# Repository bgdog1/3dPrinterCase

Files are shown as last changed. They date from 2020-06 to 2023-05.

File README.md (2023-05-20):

# 3dPrinterCase
Stand Alone Main Control Case with Modular Mounts for Various Mainboards, Display's, RPi's, Fans amd MORE!

Read the Case Guide 

Summary

I designed this Control Box out of the need for one. All the cases I found were specific to one machine and one mainboard. So if I wanted to change the mainboard or modify the machine design it quickly became obsolete. My idea behind this one is to print it once and be able to make changes as I need them. Change the screen, mainboard or RPi, just print a new mount, install it and continue. I don't have to reprint the entire thing.

The component mounts are removable and changeable so it is very versatile. I currently have plans to put this on 4 printers so the design will change from time to time. Hopefully getting better each time, so add this to your watch list. I have included mounts for the SKR mainboard's, RP3 and 4, and displays that i have and can verify fit. If I don't have it listed yet then it isnt quite ready, Sorry.

LCD Displays Currently Supported:

* LCD12864 the Original Creality Display
* TFT35 Touchscreen: BTT TFT35 V3.0 Touch Screen Display
* TFT35 Touchscreen: BTT TFT35 E3 V3.0 Touch Screen Display
* TFT35 Touchscreen: BTT TFT35 V2.0 Touch Screen Display
* More to come

For the most recent updates on my projects, join my group:
* https://www.facebook.com/groups/3DPrinterModding/

If you would like to support my work, you can use the link below. All Tips go back into the projects to be able to support more hardware. PAYPAL Link:

http://www.paypal.me/bgdog1

Currently working on:
+ Ender 5 Plus Base Case (bottom enclosure)
+ Case 6.0 Versions ALL Versions

The following files have been contributed to this project by these people. Special Thanks!

VERSION HISTORY and FUTURE DIRECTION:
All PRINTERS
- V2.0 - The first Uploads
- V2.1 - Raised the rear fan off the base for larger wire opening
- V3.0 - Customizable EVERYTHING so you can customize the set up even more. Also the Creality boards will fit in this case!!!
- V4.0 - All wiring is now internal and the entire REAR Panel print separate to be able to custmize it completely to the users needs!
- V5.0 - Reworked V3.0 Case to have Case V4.0 Rear Panel and Upper Deck
- V6.0 - Under construction. Will have larger bay for newer mainboards.

ENDER 5 PLUS

5/16/2023
+ E5Plus - Front Skirt 6 Sided 10mm wUSB Switch
+ E5Plus - Front Skirt 6 Sided 10mm
+ E5Plus - Front Skirt 6 Sided 10mm wCenter USB
+ E5Plus - Front Skirt 6 Sided 10mm wSwitch
+ E5Plus - Front Skirt 6 Sided 10mm wTempController
+ E5Plus - Front Skirt 6 Sided 10mm wTempControlUSB Switch
+ E5Plus - Rear Skirt 6 Sided 10mm wIEC
+ E5Plus - Rear Skirt 6 Sided 10mm wStock IEC
+ E5Plus - Rear Skirt 6 Sided 10mm
+ E5Plus - Side Skirt 6 Sided 10mm  wRJ45 Bottom
+ E5Plus - Side Skirt 6 Sided 10mm  wRJ45 Top
+ E5Plus - Side Skirt 6 Sided 10mm wTool Holder 1
+ E5Plus - Side Skirt 6 Sided 10mm

5/14/2023
+ Added E5P Single Control Box wFloor V2
+ Added E5Plus - Center Piece - Klipper Logo
+ Added E5Plus - Center Piece - Marlin Logo
+ Added E5Plus - Center Piece - RPi Logo
+ Added E5Plus - Center Piece - No Logo

5/13/2023
+ Added Ender 5 Plus - Base Case Component - Feet 

ALL PRINTERS
3/12/2022
+ Added Mainboard Mount - SKR V2.0

5/5/2021
+ Added TFT 5in RPi Screen Mount
+ Added TFT 5in RPi Screen Cover

3/16/2021 _ Case XL Exclusive Parts
+ Added Front Vent XL - GTR Slots
+ Added Main Body V5_0 XL GTR
+ Added Mainboard Mount XL GTR - SKR GTR V1.0dy V5_0 XL GTR
+ Added XL RPi 7in Screen Mount Lid - BTT GTR

2/7/2021
+ Added Mini Case V1.0
+ Added Mini Case - Base
+ Added Mini Case - Lid
+ Added Mini Case - BLANK Rear Panel.F3D
+ Added Mini Case - BLANK Rear Panel.STL
+ Added Display Mount Mini - Blank.F3D
+ Added Display Mount Mini - Blank.STL
+ Added Display Mount Mini - LCD12864 Stock.F3D
+ Added Display Mount Mini - LCD12864 Stock.STL

12/29/2020
+ Added Mainboard Mount - MKS GenL V1
+ Added Mainboard Mount - MKS SGenL V2
+ Added Display Mount - TFT50V30 Flush Main  Body
+ Added Display Mount XL - TFT50V30 Flush Main  Body
+ Added Display Mount - TFT50V30 Cover

10/6/2020
+ Added Rear Panel - 92mm Fan
+ Added Rear Fan External Cover 100x25mm
+ Added Rear Fan External Cover 92mm
+ Added Rear Fan External Cover 90mm
+ Added Rear Fan External Cover 80mm

10/4/2020
+ Added XL RPi 7in Screen Mount Lid
+ Added Display Mount - TFT35E3V30 SD Access Cover V2
+ Added Display Mount - TFT35E3V30 SD Access Cover V3

9/20/2020 - Starting to rework the Bases for more options
+ Added Base Front - Standard 2pc V2
+ Added Base Front - Standard 2pc V2 wSwitch
+ Added Base Rear -Standard 2pc V2
+ Added Base Rear -Standard 2pc V2 wIEC Connector
+ Added Base - Standard V2
+ Added Base - Standard V2 wIEC Connector
+ Added Base - Standard V2 wIEC and Switch

9/11/2020
+ Added Mainboard Mount Pro - Duet Wifi

9/8/2020
+ Added Display Mount XL - TFT70V30 SD Access Base
+ Added Display Mount XL - TFT70V30 SD Access Cover
+ Added Display Mount XL - Blank
+ Added Display Mount XL - Blank.F3D
+ Added Front Vent XL - Blank
+ Added Front Vent XL - Blank.F3D
+ Added Front Vent XL - BTT Slots

9/4/2020
+ Added Simple Case V2 - Main Body
+ Added Simple Case V2 - Back
+ Added Simple Case V2 - Back.F3D
+ Added Simple Case V2 - Lid
+ Added Simple Case V2 - Lid.F3D

9/3/2020
 + Added Under Table Mainboard Case - Creality V2_X
 + Added Under Table Mainboard Lid - Creality V2_X
 + Added Under Table Mainboard Case - Main Body
 + Added Under Table Mainboard Case - Lid
 + Added Under Table Mainboard Case - Lid.F3D
 + Added Under Table Mainboard Case - Back
 + Added Under Table Mainboard Case - Back.F3D

8/31/2020
+ Added Main Body V5_0 XL
+ Added Main Body Front Pro V5_0 - 2 pc Standard
+ Added Main Body Rear Pro V5_0 - 2 pc Standard

8/29/2020
+ Added Main Body V5_0 XL Compact
+ Added Base Stand XL Compact - Tall wSwitch

8/28/2020
+ Added Main Body V5_0 Pro Standard

8/19/2020
+ Added Mainboard Mount - SKR 1.4 wWIFI

8/15/2020
+ Added Main Body Front V5_0 Standard_2pc
+ Added Main Body Rear V5_0 Standard_2pc
+ Added Main Body V5_0 Compact
+ Added Display Mount - TFT70V30 SD Access Base
+ Added Display Mount - TFT70V30 SD Access Cover
+ Added Display Mount - TFT70V30 SD Access Cover

8/9/2020
+ Uploaded Old Pro Cases to Case XL folder
+ Added Base Stand Front Standard - Tall 2pc_wSwitch
+ Added Base Stand Rear Standard - Tall 2pc_wSwitch
+ Added Base Stand Standard - Tall wSwitch_IEC
+ Added Main Body V5_0 Standard

7/29/2020
- Removed V3.0 Pro Version items
- Removed V4.0 Pro Version items

7/26/2020
+ Added Display Mount - RepRap LCD12864 SD Access Cover
+ Added Display Mount - RepRap12864 SD Access  Spacer
+ Added Display Mount - RepRap12864 SD Access Main Body

7/22/2020
+ Added Base Stand - MeanWell 600w SE600 PSU Full with Switch and IEC connector
+ Added Base Stand - MeanWell 600w SE600 PSU OptionA NO Switch but has IEC connector
+ Added Base Stand - MeanWell 600w SE600 PSU OptionB NO Switch and  NO IEC connector

6/7/2020
+ Added Display Mount - TFT24V1_1 Main Body SD Access
+ Added Display Mount - TFT24V1_1 Spacer SD Access
+ Added Display Mount - TFT24V1_1 Cover SD Access
+ Added Display Mount - TFT24V1_1 Cover SD Access.F3D

6/4/2020
+ Added Upper Level Mount - SSR_1
+ Added Upper Level Mount - SSR_2
+ Added Press in Fastener for 2pc.stl
+ Added CPU Mount - Orange Pi Lite.stl

6/2/2020
+ Added Mainboard Mount V4_0 - MKSGenL_centered
+ Added Mainboard Mount V4_0 - MKSGenL_offset

5/24/2020
+ Added Base Stand Front Standard - Slim 2pc_wSwitch
+ Added Base Stand Rear Standard - Slim 2pc_wSwitch

12/29/2019
+ Uploaded original files

NOTES: The mount for the BTT SKR V1.3 also fits the BTT SKR V1.4, V1.4 Turbo, and V3 Board.

If you would like to support my work, you can use the link below.
All Tips go back into the projects to be able to support more hardware.
PAYPAL Link:

http://www.paypal.me/bgdog1

Thank you!

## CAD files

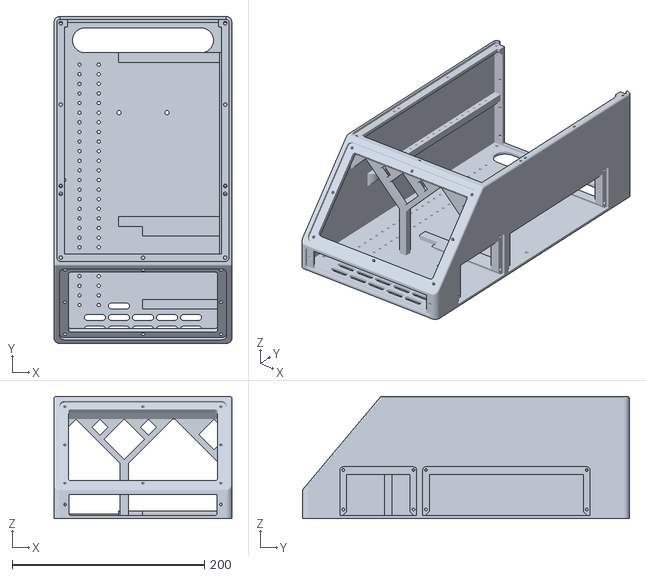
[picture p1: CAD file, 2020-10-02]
Case - PRO V5.0/Main Body V5_0 Pro Standard.stl
185.0 x 340.0 x 127.0

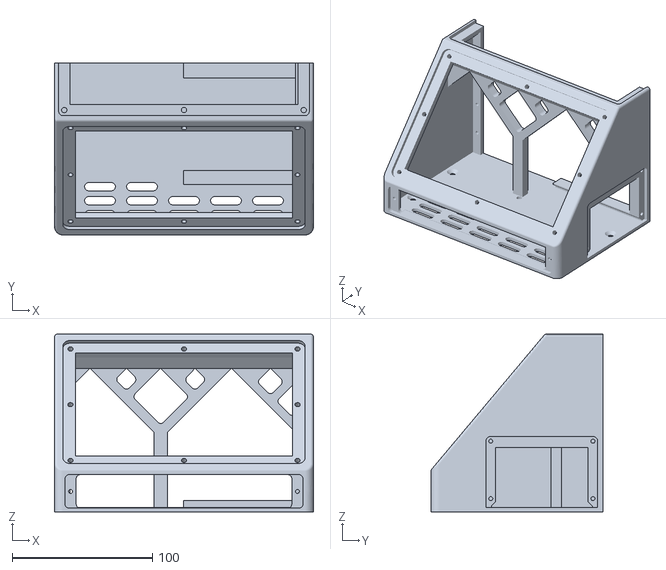
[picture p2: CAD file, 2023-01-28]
Case - Standard V5.X - 2 Piece/Main Body Front V5_1 Standard_2pc.stl
185.0 x 122.8 x 127.0

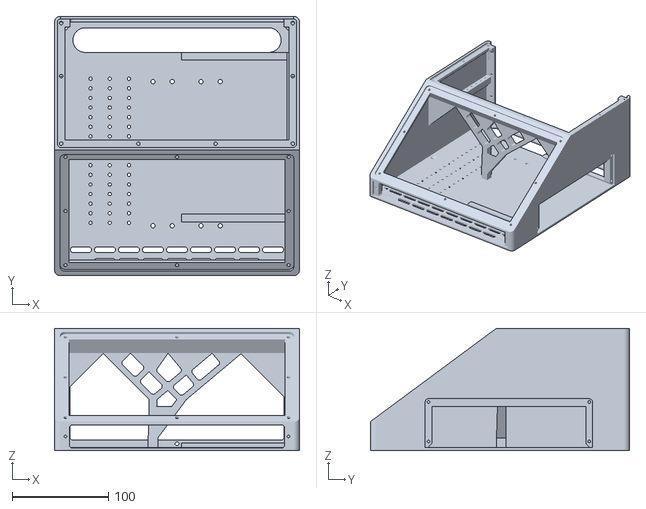
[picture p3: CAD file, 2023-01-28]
Case - XL Compact V5.X/Main Body V5_1 XL Compact.stl
255.0 x 270.0 x 127.0

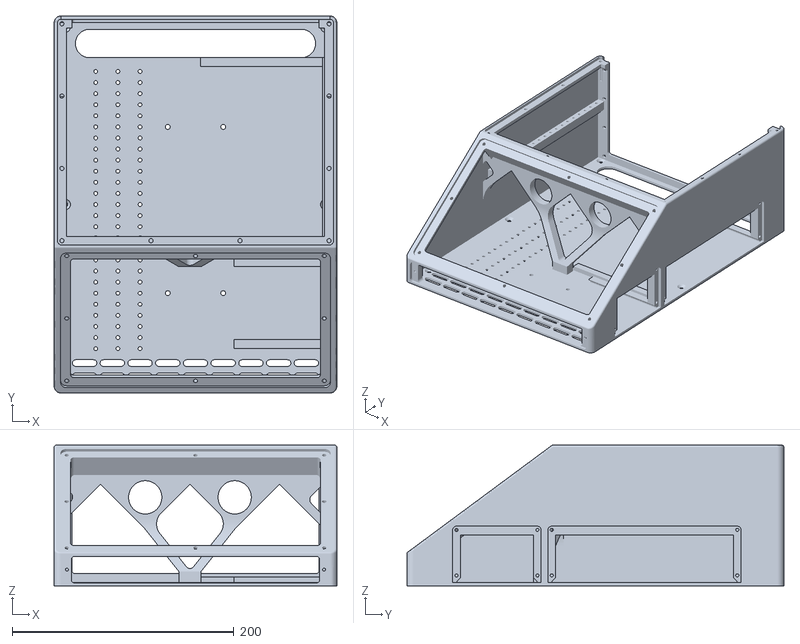
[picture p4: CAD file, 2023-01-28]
Case - XL V5.X/Main Body V5_1 XL.stl
255.0 x 340.0 x 127.0

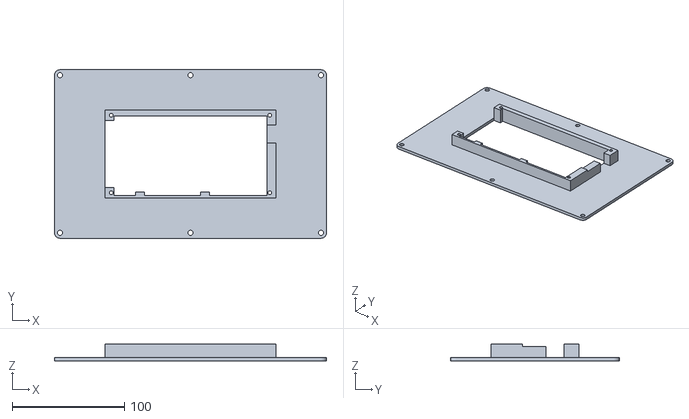
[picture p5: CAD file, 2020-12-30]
Display Mounts - XL/Display Mount XL - TFT50V30 Flush Main Body.stl
242.0 x 150.0 x 15.0

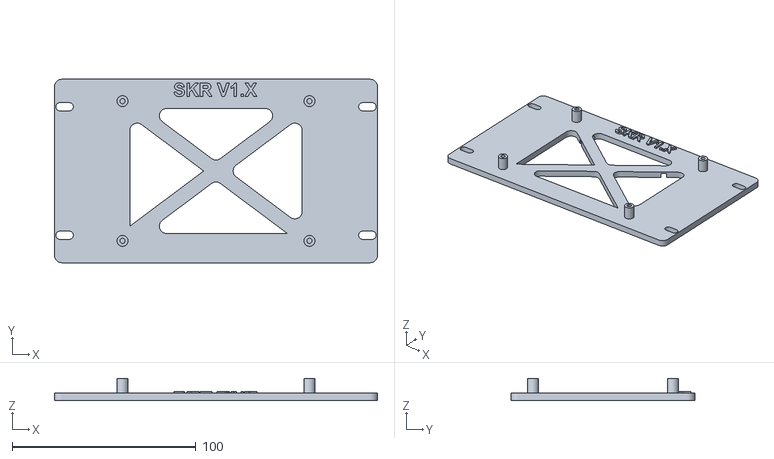
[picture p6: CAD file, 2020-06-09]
Mainboard Mounts - Case 4.0/Mainboard Mount V4_0 - SKRv1.X_centered.stl
176.0 x 100.0 x 12.0

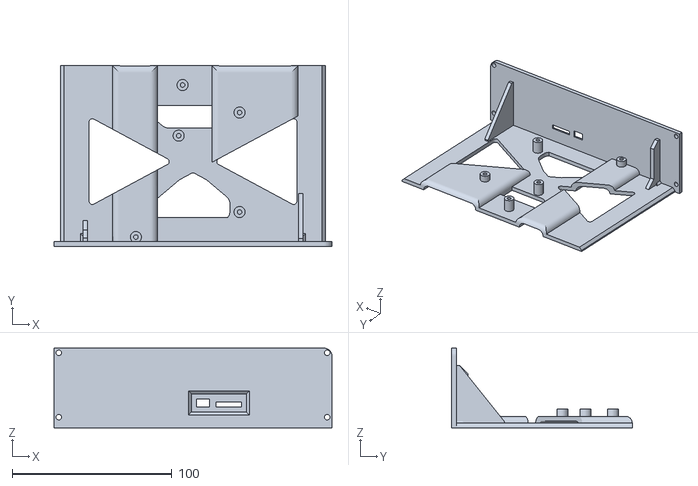
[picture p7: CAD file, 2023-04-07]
Mainboard Mounts - Pro and XL/Mainboard Mount Pro - Creality 115_SKR E3.stl
174.0 x 113.0 x 50.0

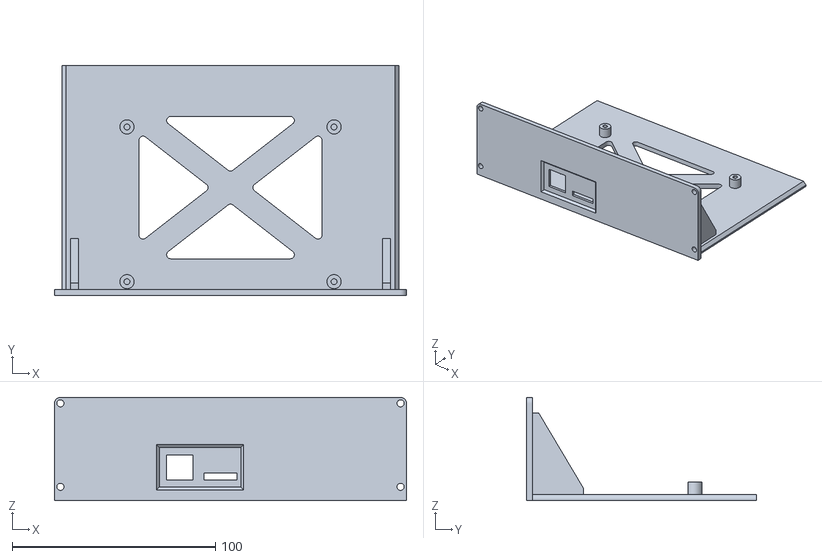
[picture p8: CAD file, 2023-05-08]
Mainboard Mounts for Pro and XL (Same) V5.x Cases/Mainboard Mount XL V5 - SKR V1.X.stl
173.1 x 113.0 x 50.7

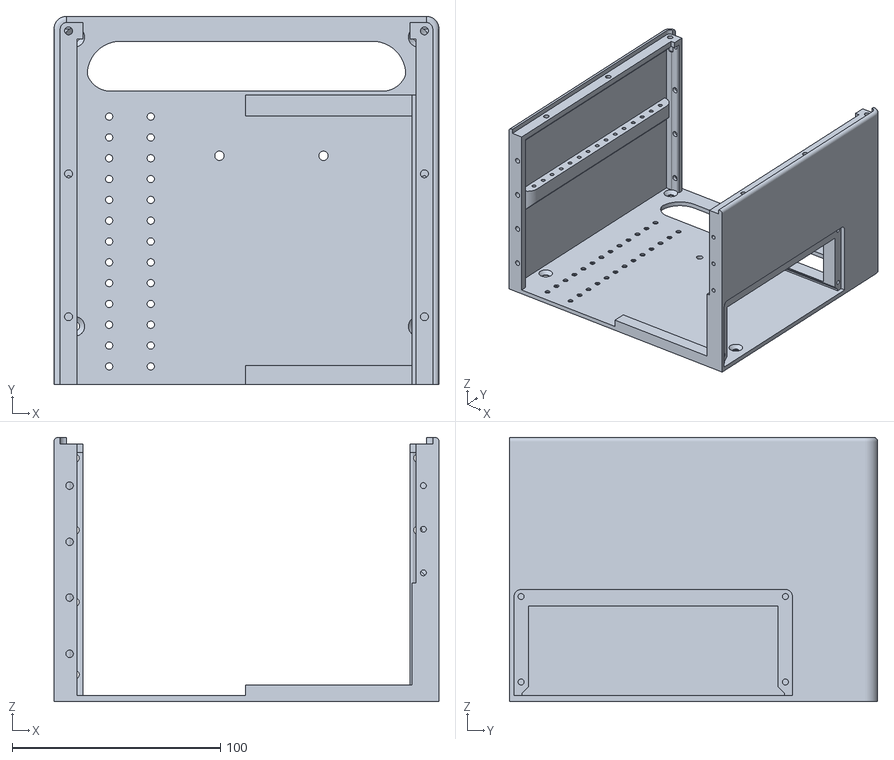
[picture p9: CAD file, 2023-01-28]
Case - Standard V5.X - 2 Piece/Main Body Rear V5_1 Standard_2pc.stl
185.0 x 177.0 x 127.0

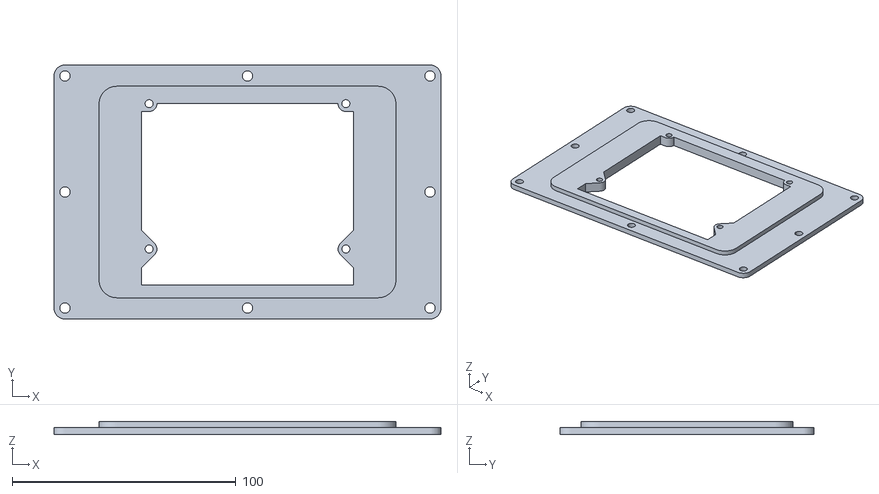
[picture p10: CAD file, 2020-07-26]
Display Mounts - Universal/Display Mount - RepRap12864 SD Access Main Body.stl
173.1 x 113.6 x 5.60

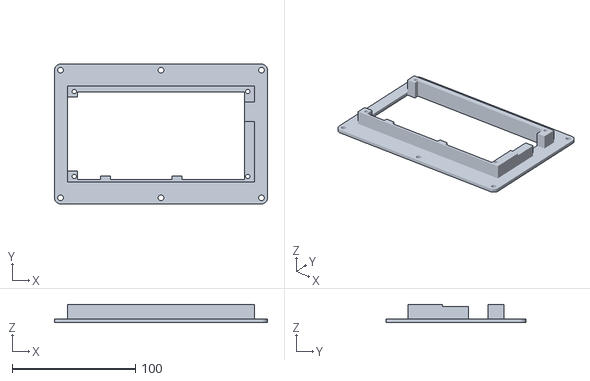
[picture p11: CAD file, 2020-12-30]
Display Mounts/Display Mount - TFT50V30 Flush Main Body.stl
173.1 x 113.6 x 15.0

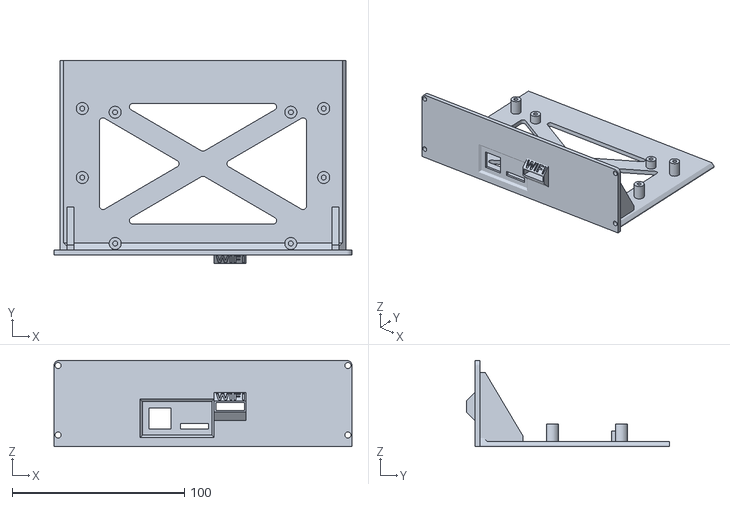
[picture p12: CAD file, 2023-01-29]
Mainboard Mounts for Pro and XL (Same) V5.x Cases/Mainboard Mount XL V5 - SKR V1.X wWIFI.stl
172.8 x 118.0 x 50.0

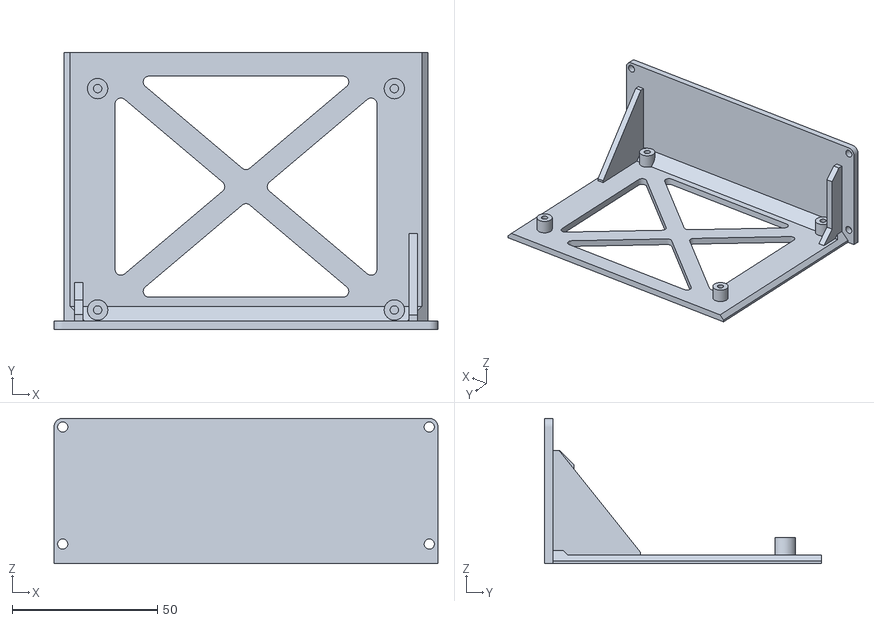
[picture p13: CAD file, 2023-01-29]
Mainboard Mounts for V5.X Cases/Mainboard Mount V2- Blank.stl
132.0 x 95.3 x 50.0

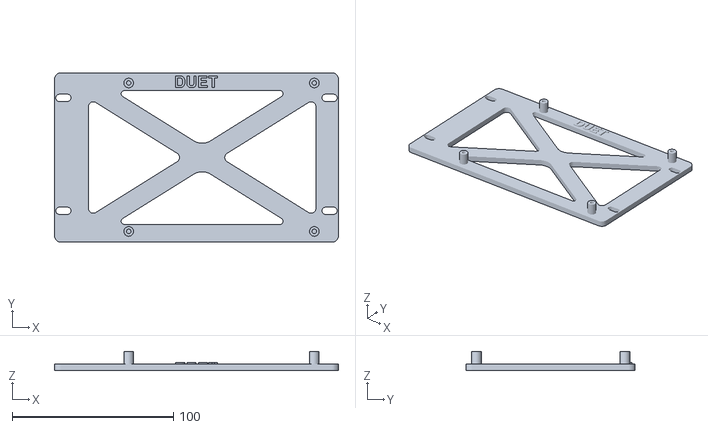
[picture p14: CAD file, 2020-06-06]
Mainboard Mounts - Case 4.0/Mainboard Mount V4_0 - Duet_offset.stl
176.0 x 105.0 x 12.0

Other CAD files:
Mainboard Mounts - Case 4.0/Mainboard Mount V4_0 - SKRv1.X_offset.stl
Mainboard Mounts for Pro and XL (Same) V5.x Cases/Mainboard Mount XL V5 - SKR V1.X wMounts.stl
Mainboard Mounts for V5.x Cases/Mainboard Mount V2 - SKR V1.3 V1.4 V3.0.stl
Rear Mount Ender 3 Case V3.0/E3 Pro Rear Case V5 - Mainboard Lid BTT LOGO.stl
Base Stand - Case 3.0 and 5.0/Base Stand - Compact.stl
Base Stand - Case 3.0 and 5.0/Base Stand Front V3_0 Standard_Slim_2pc.stl
Base Stand - Case 3.0 and 5.0/Base Stand Front V3_0 Standard_Tall_2pc.stl
Base Stand - Case 3.0 and 5.0/Base Stand Rear V3_0 Standard_Slim_2pc.stl
Base Stand - Case 3.0 and 5.0/Base Stand Rear V3_0 Standard_Tall_2pc.stl
Base Stand - Case 3.0 and 5.0/Base Stand V3_0 - Standard_Slim.stl
Base Stand - Case 3.0 and 5.0/Base Stand V3_0 - Standard_Tall.stl
Base Stand - Case 3.0 and 5.0/Terminal Cover 2pc 10mm.stl
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

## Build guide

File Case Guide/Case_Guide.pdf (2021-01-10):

# Stand Alone Main Control Case with Modular Mounts for Various Mainboards, Display's, RPi's, Fans amd MORE!!!

December 28, 2020 SB V1.2

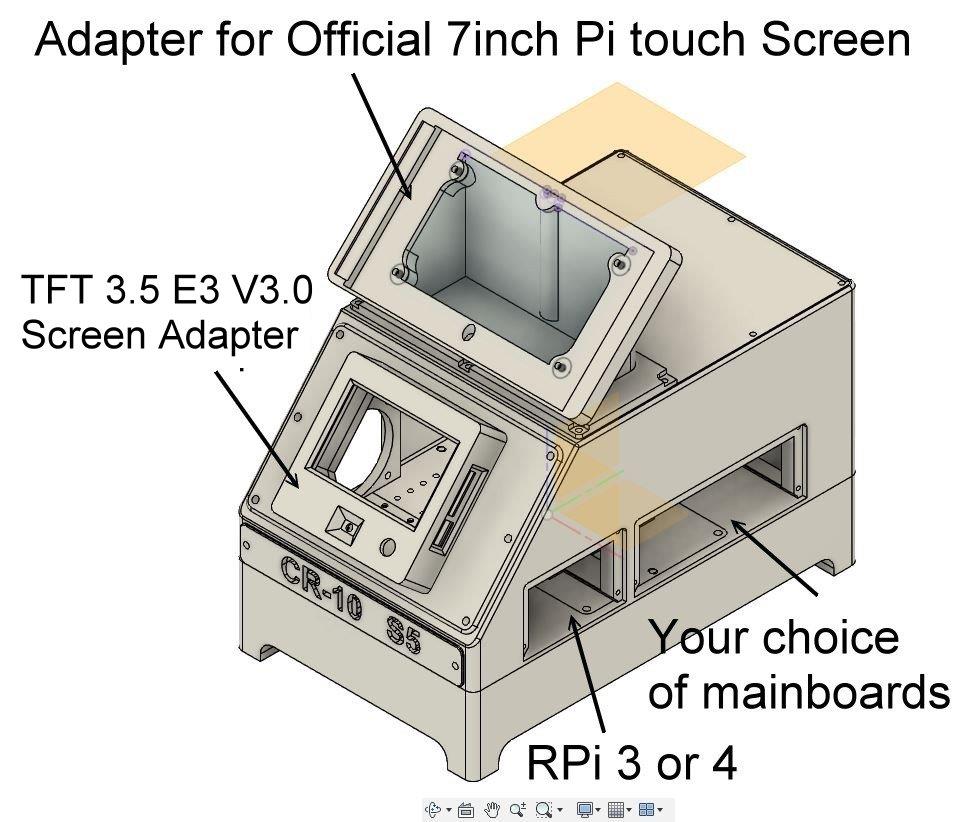
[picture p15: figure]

# Case Selection

First Decide the Size of case you need.
Compact | Standard (Recommended) | Pro | The XL
If you just want a small no frills case, minimal. This case is small and limited as to what you can do with it! | If you want a good sized case with room for all the things you want to put inside the case. | If you want a case for the bigger mainboards like the SKR Pro V1.1 | If you want a case for the bigger mainboards and 7” screens. It’s a Monster
Single Piece, need to be able to print a Part 205mm x 185mm | Single Piece, need to be able to print a Part 300mm x 185mm | Single Piece, need to be able to print a Part 340mm x 185mm | Only one option here, a single print. You will need to be able to print a Part 340mm x 255m. This Case will not be available in multiple pieces because of its size!

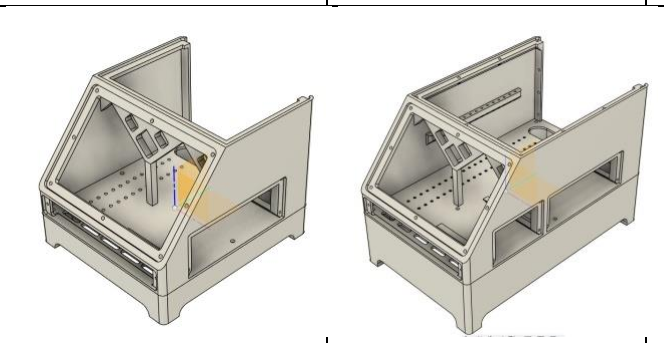
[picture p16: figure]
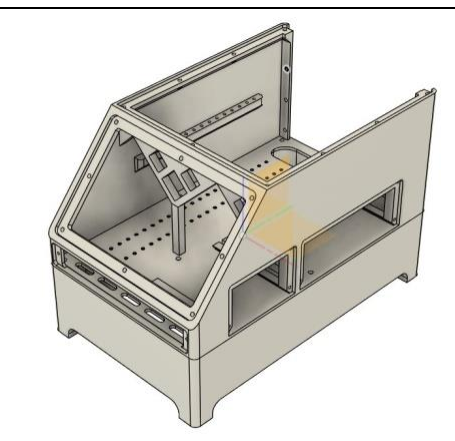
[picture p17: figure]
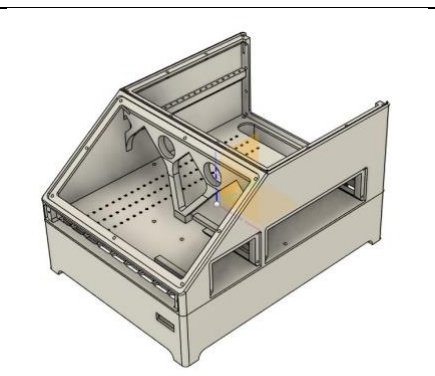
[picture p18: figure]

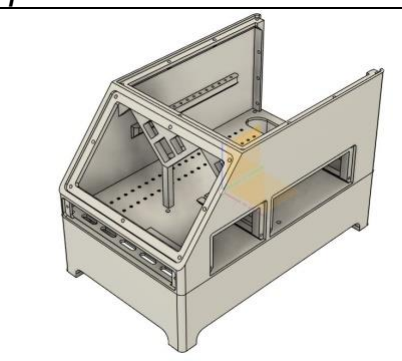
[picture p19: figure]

Standard 2 Piece, if
you need to be able to
print on a smaller
printer like an Ender3

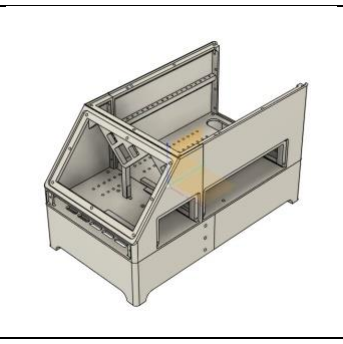
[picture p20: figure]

Pro 2 Piece, if you need to be able to print on a smaller printer like an Ender3 You will need to be able to print a Part 217mm x 185mm

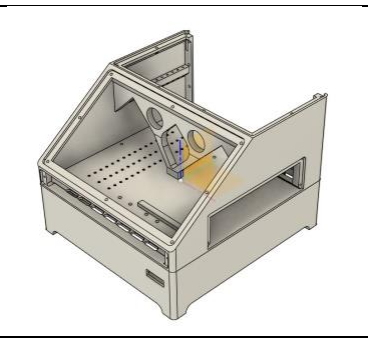
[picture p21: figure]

XL Compact, If you don’t need a RPi in the case but you want the larger case for the mainboard and 7” screen.

## Select your Mainboard Mount

Pick the Mainboard Mount for the board you are going to install, I.e. SKR v1.3, Creality board, etc.

Example: SKR V1.3 or higher = Mainboard Mount - SKR V1.

Creality 1.1.3 or Mini E3 = Mainboard Mount - Creality 115_SKR E3

## Select your Display Mount

Pick the Display Mount for the display you are going to install, I.e. TFT 3.5 V3, LCD12864, etc.

Many LCD Displays Currently Supported. Same file formatting.

Some Display Mounts are available 2 ways, with SD card slot access (raised) and without (flush).

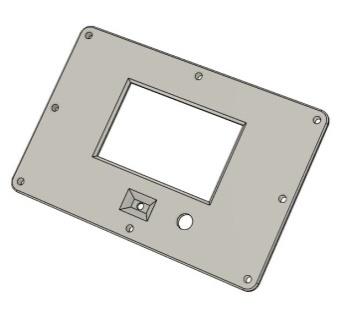
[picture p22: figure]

Example (Flush):TFT 3.5 E3 V3.0

Display Mount - TFT35E3V30

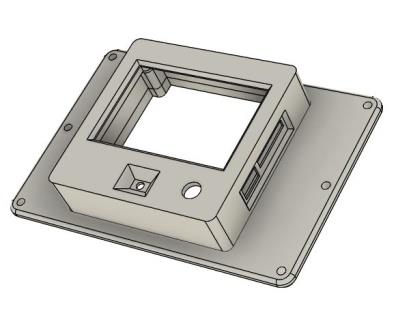
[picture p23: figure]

Example (Raised multiple pieces):

Display Mount - TFT35E3V30 SD Access Body

Display Mount - TFT35E3V30 SD Access Spacer

Display Mount - TFT35E3V30 SD Access Cover

## Select your CPU Mount

Pick the CPU Mount for the RPi you are going to install. I.e. Pi 3 or 4. Same file format as the other files.

Select the appropriate lid for the case, Compact, Standard, or Pro.

There is a Mini, Compact, Standard, Standard 2 piece, Pro, Pro 2 piece, and XL versions of the lid. Select the appropriate version for your case. Same file format as the other files.

## Internal Fan

There are several double 4020 fan mounts to choose from.

Not everyone uses the internal fans, some use a lid mounted fan. Your choice.

## Front Vent

There are several front vents to choose from, print and install.

## BLANKS

Many components have a blank version. Use this if want to create your own component.

## Fan Hats

This gives you the option to mount components like Buck Converters and MOSFET’s on top of the 4020 fans. Since there are way too many possible combo I have elected to post thee necessary files for you to create the combo you need.

## Rear Panel

There are 3 sizes of the Rear Panel, Mini, Standard and XL.

The Mini rear panel only fits the Mini

The Standard rear panel fits all cases including the Compact, Standard, 2pc Standard, Pro, and Pro 2 pc.

XL, fits only the XL and XL Compact Cases.

## Finally!

Print your files, assemble, and wire it anyway you see fit.
Check out the Post Topic “Great Examples” for images of previous assemblies.

## Printer Settings

All Printers:

Infill = 20% or More

Supports = YES, MAX Overhang Angle = 55 degrees

T-Frame printers (Ender 3):

Speed - 50 mms or slower

Nozzle Temp – Print a temp tower to determine the best temperature setting for your filament.

PLA https://www.thingiverse.com/thing:3477606

PETG https://www.thingiverse.com/thing:4229915

Bed Temperature - Any

Cube style (Ender 5):

Speed – 50 mms or slower

Nozzle Temp – Print a temp tower to determine the best temperature setting for your filament.

PLA https://www.thingiverse.com/thing:3477606

PETG https://www.thingiverse.com/thing:4229915

## RECOMMENDED PRINTING ORIENTATION

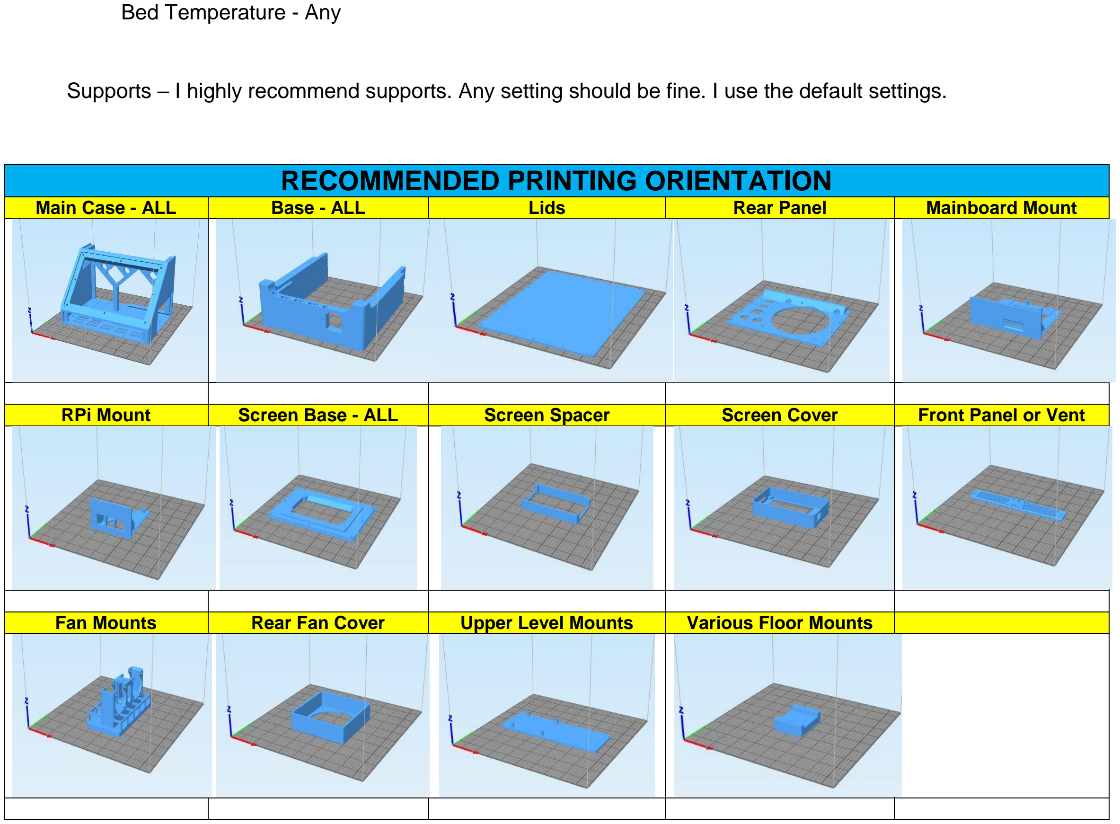
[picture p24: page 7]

Bed Temperature - Any

Supports – I highly recommend supports. Any setting should be fine. I use the default settings.

Main Case - ALL | Base - ALL | Lids | Rear Panel | Mainboard Mount
RPi Mount | Screen Base - ALL | Screen Spacer | Screen Cover | Front Panel or Vent
Fan Mounts | Rear Fan Cover | Upper Level Mounts | Various Floor Mounts

Compatibility Chart
| Mini | Compact | Standard | Standard 2 Pc. | Pro | 2 Pc. Pro | XL | XL Compact
Mini Lid | Yes | No | No | No | No | No | No | No
Compact Lid | No | Yes | No | No | No | No | No | No
Standard Lid | No | No | Yes | Yes | No | No | No | No
Pro Lid | No | No | No | No | Yes | Yes | No | No
2 Pc Pro Lid | No | No | No | No | No | Yes | No | No
XL Lid | No | No | No | No | No | No | Yes | No
Compact XL Lid | No | No | No | No | No | No | No | Yes
Mini Rear Panel | Yes | No | No | No | No | No | No | No
Rear Panel | No | Yes | Yes | Yes | Yes | Yes | No | No
Mainboard Mount - XXX | Yes | Yes | Yes | Yes | Yes | Yes | No | No
Mainboard Mount Pro - XXX | No | No | No | No | No | No | Yes | Yes
CPU Mount - ALL | No | Yes | Yes | Yes | Yes | Yes | Yes | No
Display Mount Mini | Yes | No | No | No | No | No | No | No
Display Mounts | No | Yes | Yes | Yes | Yes | Yes | No | No
Display Mount XL | No | No | No | No | No | No | Yes | Yes
Fan Mounts | No | Yes | Yes | Yes | Yes | Yes | Yes | Yes
Front Vents | No | Yes | Yes | Yes | Yes | Yes | No | No
Front Vents XL | No | No | No | No | No | No | Yes | Yes

## !! NOTE the Mini is not yet available. Coming Soon

## Where does the PSU mount?

The PSU mounts underneath the case. Unless you printed the Compact Case. Not enough room in this case design.

Connect with M3 x 6mm button head screws, NO longer than 6 mm. You could cause damage/

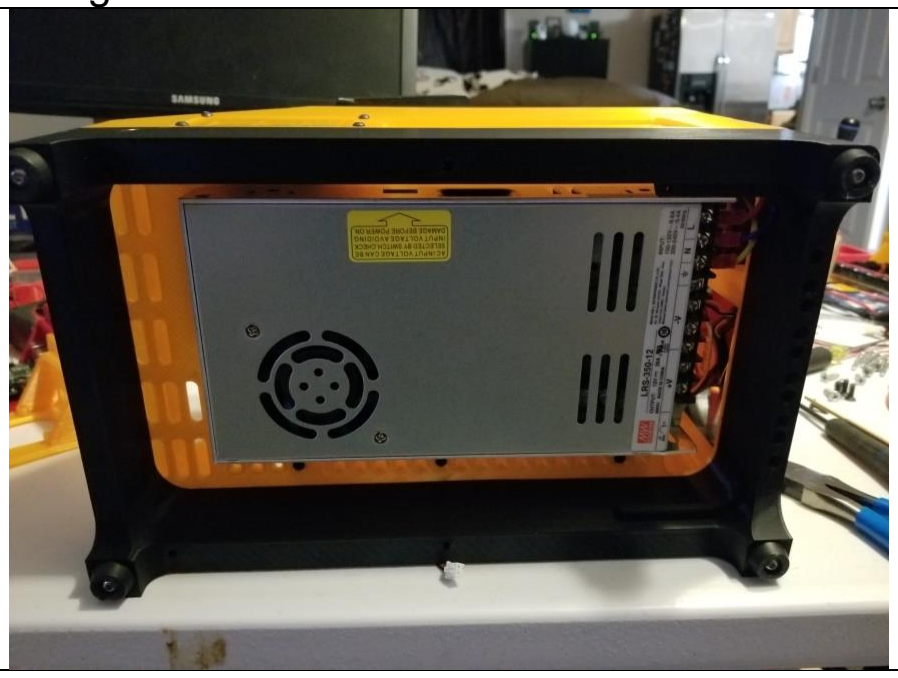
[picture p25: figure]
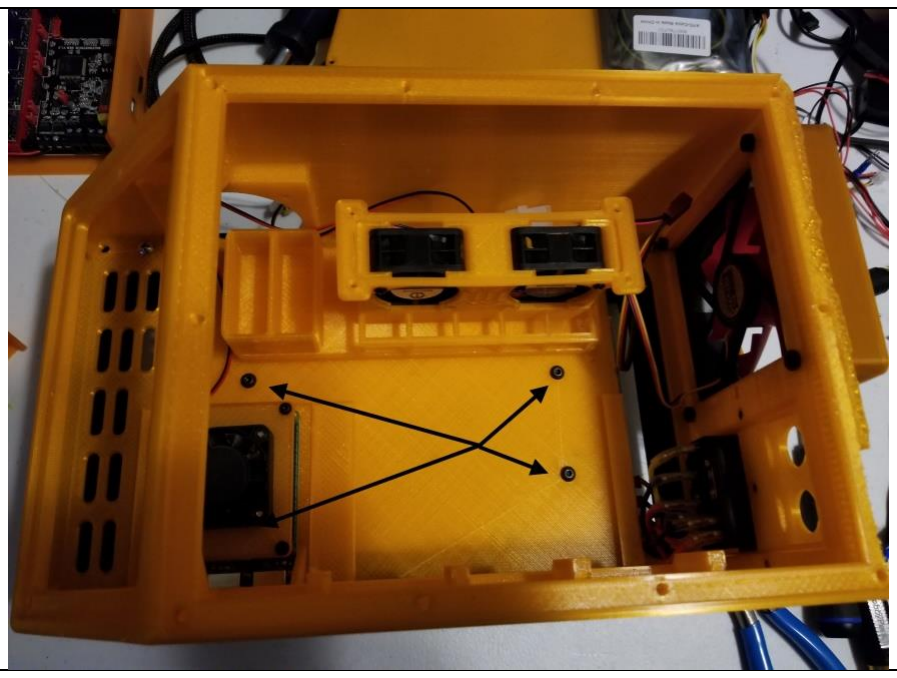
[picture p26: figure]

## Fasteners (Recommended sizes are not absolute)

Main Body to Base

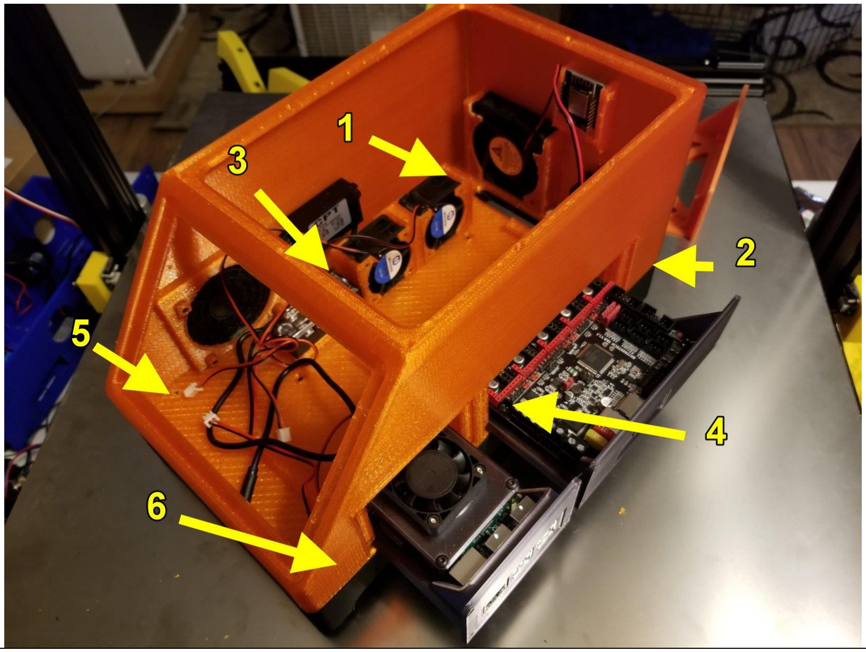
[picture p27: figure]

M4 x 16 Button
Head Screws

or

#8 x ¾ Sheet Metal

Screws

or

#10 x ¾

Sheet Metal Screw
s

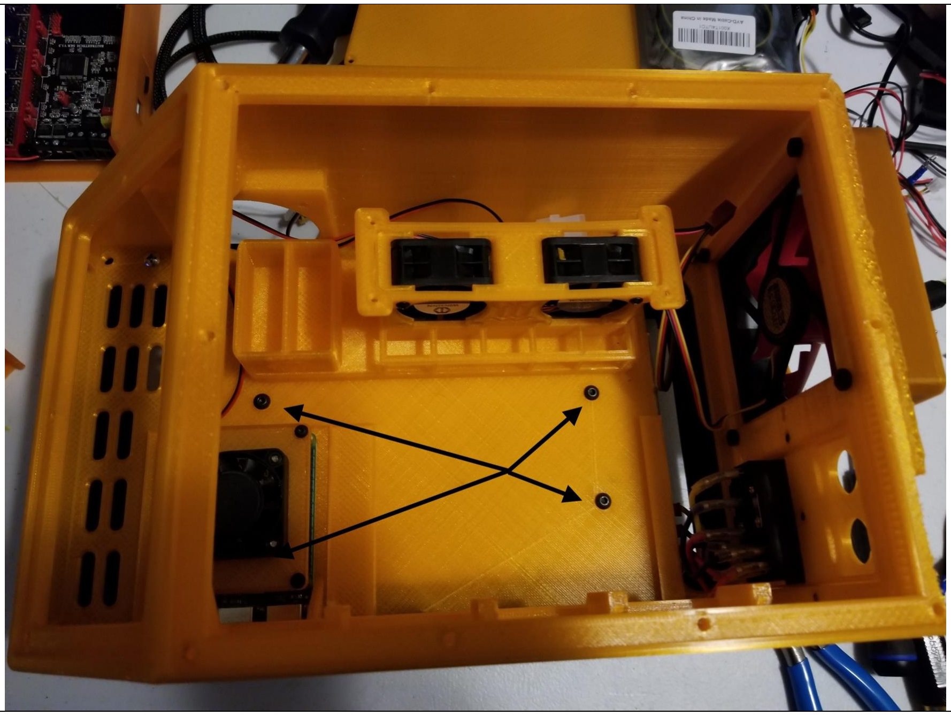
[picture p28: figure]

PSU to bottom of
Main Body

M4 x 6 Button Head
Screw

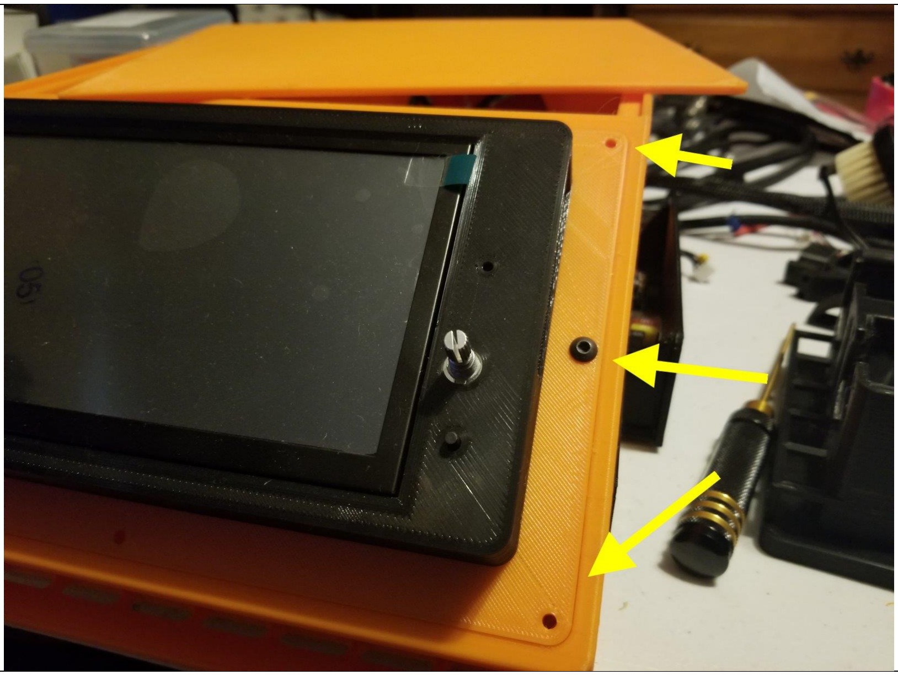
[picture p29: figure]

Front Display
Mount

M4 x 12

Most displays
attach to the mount
with M3’s of
various lengths.

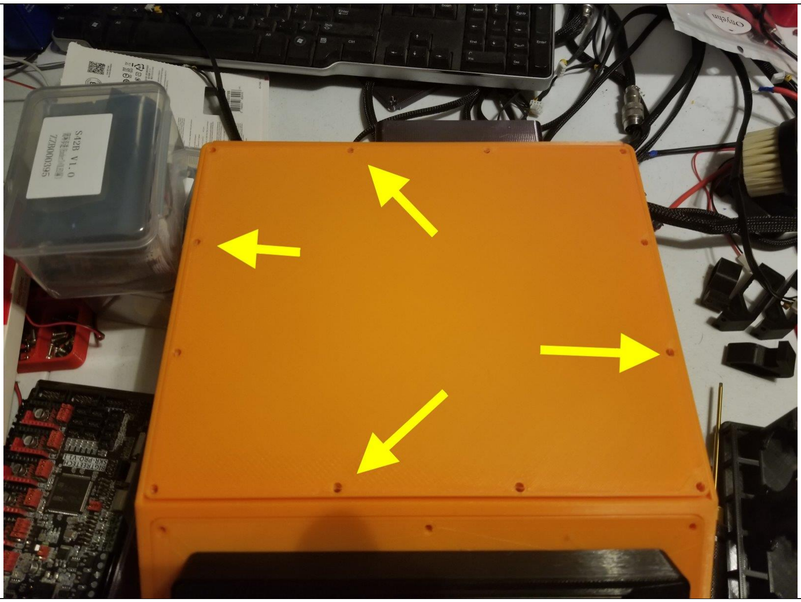
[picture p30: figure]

Lid

M4 x 12

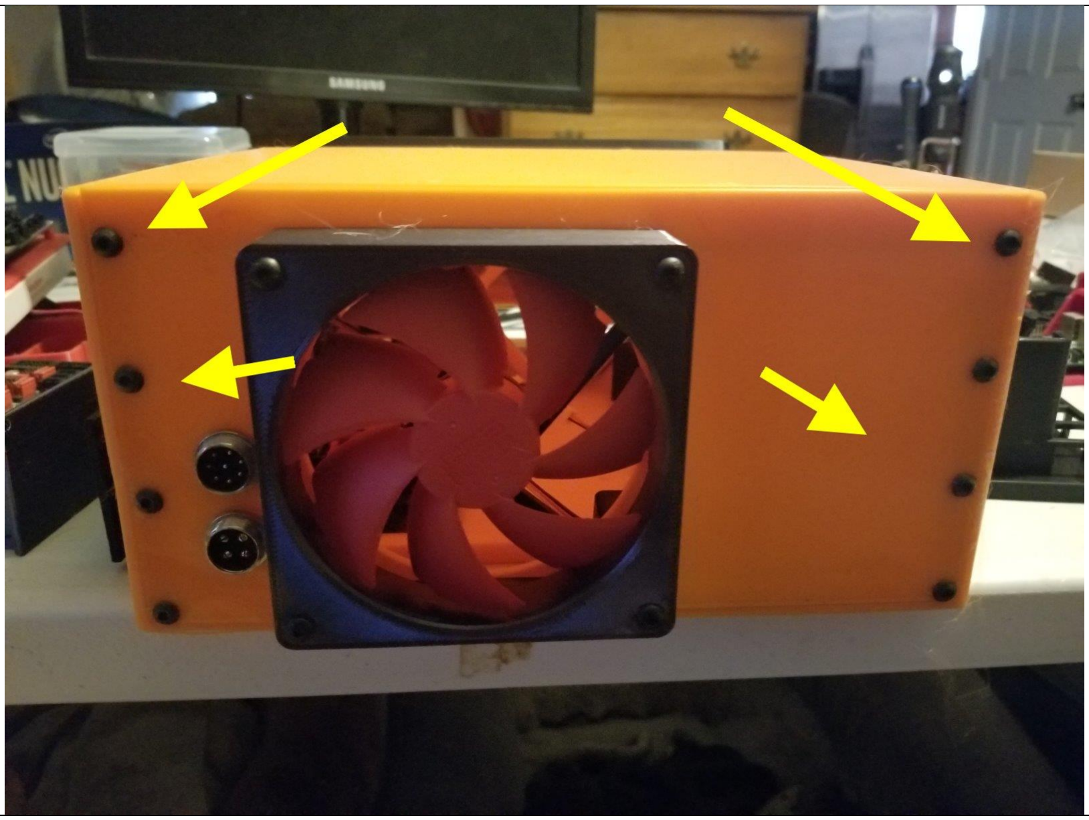
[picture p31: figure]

Rear Panel

M4 x 12

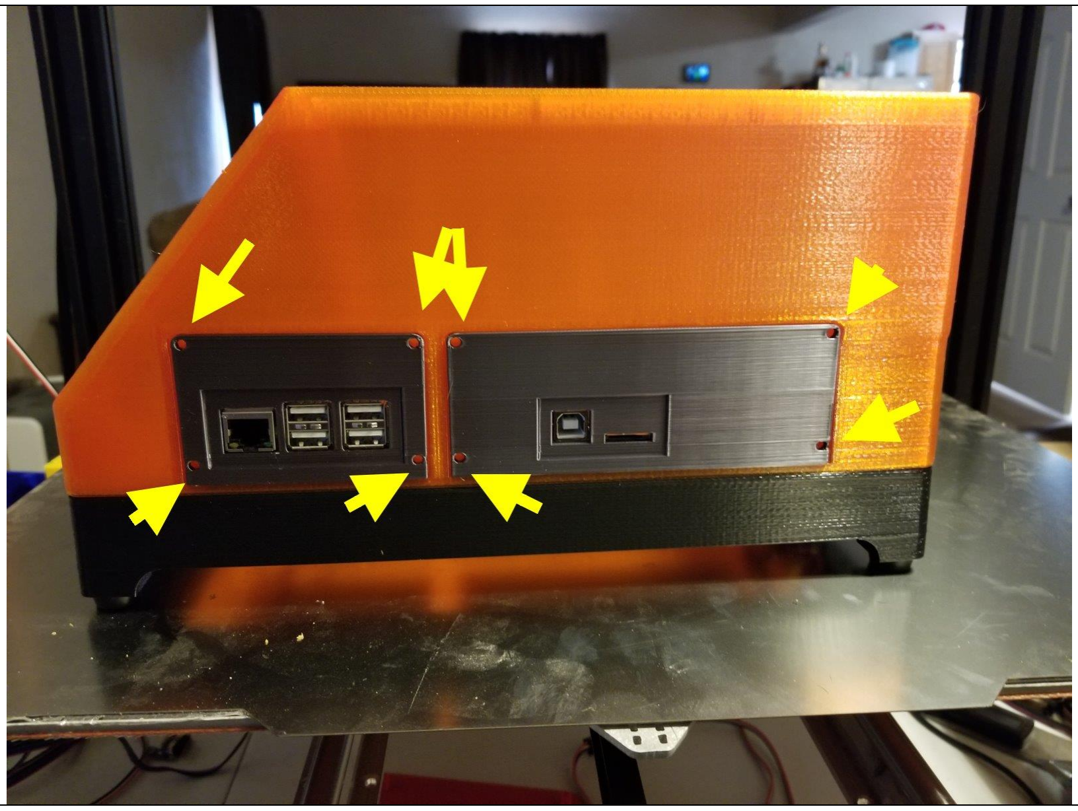
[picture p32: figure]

Bay Mounts

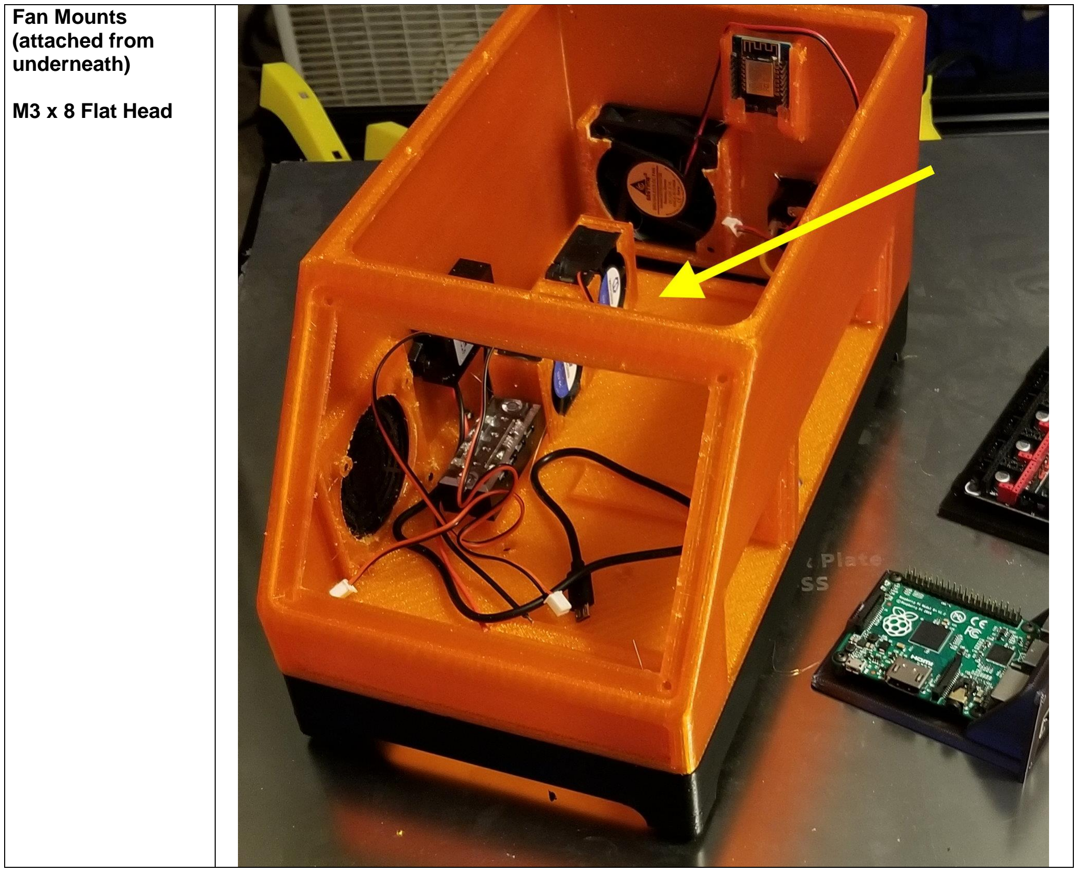
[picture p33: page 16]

Fan Mounts
(attached from
underneath)

M3 x 8 Flat Head

Accessories:

## Raspberry Pi 7 inch Touch Screen (Official)

1. Install the screw on the inside of the base mount to the lid (3- M4 screws)
2. Set the screen in the screen mount an use 4- M3x12 socket head screws to attach the screen and the mount at the same time. 2 from under the lid thru the opening and 2 from the top behind the base mount. Be careful not to over tighten these screws.
3. Do the wiring.
4. Attach lid to case.
5.

## Solid State Relay Floor Mounts

!!!! Caution!!! When SSR’s fail, they usually fail closed. This means that if it fails, the bed will heat to its max temperature and the printer controls will not be able to control it. This could easily start a fire. Always use a Secondary Method of Thermal Runaway Protection!!! One that monitors the bed temperature and sits idle until the temperature goes above a setpoint, i.e. 120 degrees C. Then will kick in and prevent it from getting any higher.

## Parts:

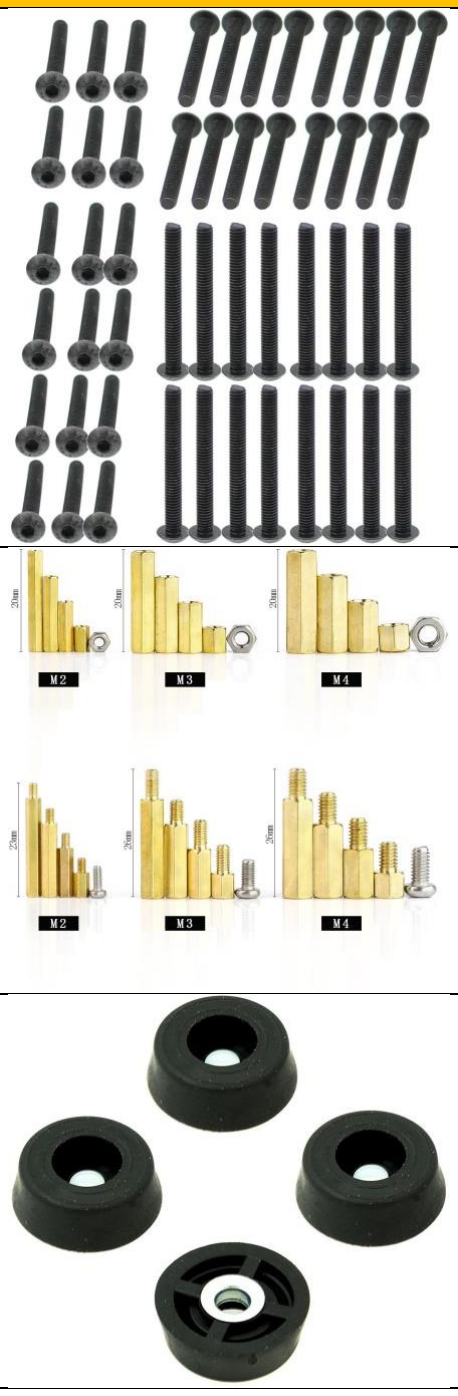
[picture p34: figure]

Screws; Miscellaneous M3 and M4 Bolts Miscellaneous M3 and M4 Nuts 8x3/4 or 10x3/4 sheet metal screws (to attach the base)

M3x15 brass standoff - to mount the fan board on the RPi

Small Round Rubber Feet W/Screws - .250 H X .671 D

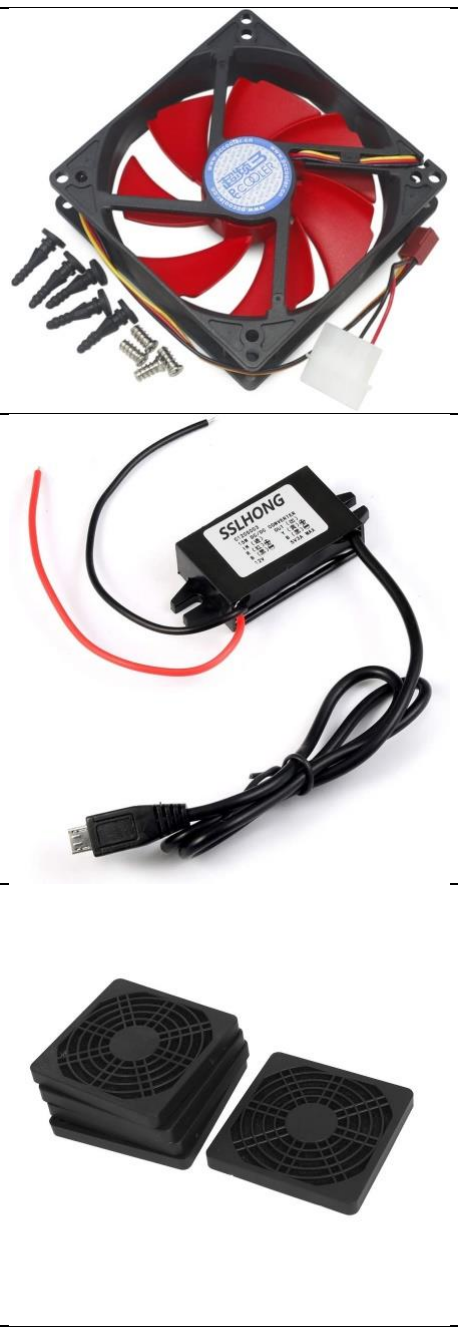
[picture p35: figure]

(If you are using this on a 24VDC system, then get the appropriate 24v parts, 12VDC then those appropriate parts.)

Buck Converters: HOMREE DC-DC Converter Step Down Module 12/24V to 5V Micro USB Output Buck Power Adapter (Micro USB) - power for RPi 2/3

Dust Covers: 100, 92, 60mm Black Plastic Dustproof Case Fan Dust Filter Guard Grill Protector Cover PC Computer Pack of 5

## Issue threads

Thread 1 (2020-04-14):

Can't Print on Maker Select v2

reynolds087, 2020-04-14:
The maker select v2 has a limit of 200 x 200. Is there any option for case that can be printed on a bed that small?

bgdog1, 2020-04-26:
Sorry

bgdog1, 2020-04-27:
The 2 pc will print on that size if you print the longer of the 2 base pieces standing upright. I will correct this in thw 2pc 4.0 case.

Closed 2020-04-27.

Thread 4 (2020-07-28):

Fusion 360 Source Files?

jpflouret, 2020-07-28:
Great Project! I've been searching for exactly this. I'd like to print the V4 Base Standard 2 piece tall but with a different power inlet/switch (Specifically this one: https://www.amazon.ca/dp/B07S6M451F/ref=cm_sw_em_r_mt_dp_U_Lm-hFbWHF2XZX). I see there are some f3d files in the depot for some parts so I would like to modify the parts that I need and it would be so much easier to do that on the source files. If you share the source files I can share back the modified stl files.

Thanks and keep up the good work.

bgdog1, 2020-08-09:
Done

Closed 2020-08-09.

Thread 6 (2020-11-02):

Documentations

veskoz, 2020-11-02:
Hi,
First off thanks for the work you have done, i feel like there is not enough documentations on what has to be printed or which version of the case has that the others do not.. also the Case - Modular Under Table seems like just a case where u can only slide 1 piece..it's all a little bit confusing.. don't take it badly i just wanna try to help

DannyGlover, 2020-11-05:
Hi @veskoz, I think the language barrier is against us here.

I understand you see issues with the documentation.. But I can't decipher which documentation you are referring to. Are you talking about this? https://docs.coronalabs.com/api/index.html

Thank you.

veskoz, 2020-11-05:
Hi,
I was referring to the 3dPrinterCase.
For instance i'd like to have the case under my table, but can't understand what do i have to print.
This is what i have: pi4,sk1.4turbo with wifi module, 2 mosfets, LCD12864
I think i have to go with `https://github.com/bgdog1/3dPrinterCase/blob/master/Case%20%20-%20Modular%20Under%20Table/Under%20Table%20Mainboard%20Case%20-%20Main%20Body.stl`
But imho seems like that case can only fit one slidable piece

DannyGlover, 2020-11-05:
Ah, I see. Got mixed up there @veskoz .

I am not the author of the case. I simply forked the repo for my own use. You should take this up with the original creator.
Thank you

j0r1svdb, 2020-12-02:
There's a PDF called 'Case_Guide V*.*.pdf" at the Facebook page linked in the Readme (https://www.facebook.com/groups/3DPrinterModding/files).
This could indeed be made more obvious.

bgdog1, 2020-12-04:
Documentation has been moved to the Facebook Group. https://www.facebook.com/groups/3DPrinterModding

Closed 2020-12-29.

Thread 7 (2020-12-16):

mainboard mount MKS SGEN_L

doug-scott, 2020-12-16:
I see in the readme.md that these two mounts were created a few months ago:

6/2/2020
Added Mainboard Mount V4_0 - MKSGenL_centered
Added Mainboard Mount V4_0 - MKSGenL_offset

I cannot find them.  Are they still applicable to v5 cases?

doug-scott, 2020-12-22:
Have the rest of the case printed, just need the mainboard mounts for my MKS SGEN_L board.  The readme.md says they were added back in June, but I cannot locate them on Thingiverse, Facebook or here.

doug-scott, 2020-12-26:
I found the two mainboard mounts by stumbling onto 'bgdog1' changes and going back to June 2, finding where they were inserted into v4 components.  I do not know if they are v4 specific yet, haven't printed them yet.  Don't see why not, they are just simple flat adaptor plate.  Also grabbed the v4 front and rear standard body shells just in case.  Those cases actually fit my system better, they don't have any of the side openings, and since the mainboard mount does not insert through the side like the other mounts do, that means I don't need them.  The front display mount suits my needs, as does the lower grille when the SD card mounts are added to the slotted grill from within S3D.  I do not know how to use any of the graphic apps, so I just inserted 2 of the SD card adaptor mounts into the slotted grill, then print that part out, and trim the excess slotted grill that is printed into the SD mounts.  I have a SD mount on either side of the grill to allow access to the SD card sockets on the TFT and the mainboard.

Closed 2020-12-26.

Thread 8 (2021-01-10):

Pro V5 2pcs & standard V5 2pcs questions tops & bottoms.

craftyham, 2021-01-10:
Are the ProV5 2pcs bases the same hole placement & size as the standardV5 bases with the plug cut outs? I have to re print the bases. & have the main body rear pro standard V5 printed along with both pro lids and display parts. Can all the proV5 and V5 standard  2pcs parts be interchanged? I like the bases with the plug & switch.

bgdog1, 2021-01-10:
There is a compatability chart in the guide.

Closed 2021-01-10.

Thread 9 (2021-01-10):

proV5 board mounts

craftyham, 2021-01-10:
what board mount file would be used for on the pro V5 or standardV5 to run the E3mini1.2

bgdog1, 2021-01-10:
The SKR Mini E3's are the same size and have the same hole pattern as the Creality 1.1.5 so use the Creality mount. There isn't a mount for the Pro, it is for the larger boards like the SKR Pro.

Closed 2021-01-10.

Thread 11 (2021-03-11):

SKR Pro v1.2 on 230x230 Printer

JustLew3, 2021-03-11:
Has anyone modified the XL to 2 piece or widen the slot in Pro to accept the SKR Pro? I love this case design, but I cannot print it for my mainboard sadly.

gulah, 2021-06-20:
I used this https://github.com/bgdog1/3dPrinterCase/blob/master/Mainboard%20Mounts%20-%20Pro%20and%20XL/Mainboard%20Mount%20Pro%20-%20SKR%20Pro%20V1.1.stl to mount an SKR PRO v1.1 in a 2 piece pro case. I believe the boards are the same dimensions? Apologies if I'm mistaken.

bgdog1, 2021-07-11:
The XL is too big to split for printing on smaller printers. Even the display mount wont print on a smaller printer.

bgdog1, 2021-07-11:
The Pro mounts fit the Pro cases

Closed 2023-01-29.

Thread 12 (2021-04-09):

Pro 2 Piece Base missing Switch variant

RoyalStarfox, 2021-04-09:
I'm going through and gradually printing each part of the case (Which they're amazing, by the way! Thanks!) and I noticed that the 2 piece variant of the Pro Base doesn't have a file that includes the slot for the power switch. Can that be added in?

RoyalStarfox, 2021-04-09:
Also the Pro Cases don't have a PSU terminal cover for their size, either.

gulah, 2021-06-20:
I also was looking for this configuration so I threw something together from the STL and took the switch and power outlets dimensions from the regular Pro Base. It required a tiny bit of hand working for the outlet i had from my CR-10 after printing.
[BaseStandRearV5_0Pro_2pc-wSwitchandIEC.zip](https://github.com/bgdog1/3dPrinterCase/files/6683062/BaseStandRearV5_0Pro_2pc-wSwitchandIEC.zip)

bgdog1, 2021-07-11:
I am working towards redoing all the bases to be more universal. These items will be in the V2.0 bases.

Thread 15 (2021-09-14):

Base Rear -Standard 2pc V2 wIEC Connector.stl missing holes for rubber feet screws

Ganjalf-TD3D, 2021-09-14:
Base Rear -Standard 2pc V2 wIEC Connector.stl missing holes for rubber feet screws (like in the front part)
the case over all is awesome tho!

bgdog1, 2022-03-13:
Uploaded most recent version

Closed 2023-01-29.

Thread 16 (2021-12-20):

SKR turbo 1.4 wont fit with ferruled connectors

pearlsails, 2021-12-20:
just like it says on the tin, the board needs about 10 mm more room to get the ferruled connectors in, or it just hits against the frame. I am doing the 2 part here, so that may be why.

bgdog1, 2022-03-13:
Can you provide a pic of the issue? Thanks

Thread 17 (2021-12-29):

Request for .step files to make iterations easier

markdhooper, 2021-12-29:
Love the project, thank you for all of your hard work.

I was wondering if .step files could be added in addition to .stl files.

.step files are compatible with nearly all CAD programs.

.stl files are pretty difficult to edit, and there are some .f3d files present. Which is useless to someone without fusion360.

There are some modifications that I would like to make/versions of .stl files floating around on the Facebook group that aren't present in other form factors for myself/folks in the Facebook group. But the only thing holding me back from doing so is that the majority of these files are available only as .stl files.

Thanks again.

bgdog1, 2022-03-13:
Step files for what components. I wont post them for them cases.

Nathan22211, 2022-07-08:
Probably for the entire system. .step files are preferred because we can edit them in any compatible software. FreeCAD would come to mind

Closed 2023-01-15.

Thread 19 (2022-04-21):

Request for a BTT Octopus v1.1 board

ROADwarrior82, 2022-04-21:
Good Afternoon,

I just built this for my Ender 3, and it's awesome. I am about to change to an Octopus on another enclosed printer, and I would love to use this control box, but there is not an Octopus tray in the mainboard section.

Thanks.

jon-harper, 2022-05-09:
It will not fit in the stock case; you have to use the XL version. I am finalizing a redesigned case with the original footprint, but that's the only way to get an Octopus to fit in the stock case--the trays are not large enough.

ROADwarrior82, 2022-05-09:
Awesome. Thank you. I actually couldn't get the octopus to connect, so I ended up returning it and got a SKR 2 instead. Thank you for the response. Loving the case I am using for my Ender 3.

bgdog1, 2023-01-15:
I found a CAD file for the Octopuss V1.1 board. I will see what I can do for a mount.

Closed 2023-05-10.

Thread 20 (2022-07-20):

RPi Bay mount screw hole sizing

talentedmrripley, 2022-07-20:
The hole size on the Pis is 2.5mm but the mounting posts seem to be setup for an M3 fastener.  You can force an M3 through the mounting holes but it's not ideal.  I have only printed and tested this with the Pi 4 mount, so perhaps it's not an issue on any of the rest.  But on the Pi 4 mount at least it should be corrected.

bgdog1, 2023-05-10:
I drill the hole out to 3.2mm. A 2mm screw is just too small.

Closed 2023-05-10.

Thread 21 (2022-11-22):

Case V5 and Pi mount sizing

Otann, 2022-11-22:
I was checking how it would look like together in Fusion 360 and that seemed off scale to me.
The holes for the screws almost match, but not quite like all other parts fit together.

Am I missing some settings or using an older version?

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

truelecter, 2023-01-19:
Same for Compact Version. Quick align shows that  mount points are a bit larger than bays are
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

Otann, 2023-01-24:
@truelecter I can recommend you this project that I've sound and successfully completed.
And it can be printed on a smaller printer, like Ender 3

https://github.com/jon-harper/OmniBox

truelecter, 2023-01-24:
Thank you, that is just what I was looking for!

Closed 2023-01-29.

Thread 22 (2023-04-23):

Request for a ender 3v2 4.2.2 / 4.2.7

drveni, 2023-04-23:
please for board

bgdog1, 2023-04-24:
I think that board has the same dimensions as the 2.1 and 2.2 boards. Try printing the file Mainboard Mount V2 - Creality V2_1+.stl and see if that fits. Let me know the outcome please.

drveni, 2023-04-26:
V2 fits!
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
![Uploading PXL_20230425_174412168.jpg…]()

bgdog1, 2023-05-02:
Thanks for the feedback. Much appreciated.

Closed 2023-05-02.

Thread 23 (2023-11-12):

BTT SKR MINI E3 V3.0

pyrosuperman, 2023-11-12:
Can you add the Big tree tech "SKR MINI E3 V3.0' mainboard trays?

pyrosuperman, 2023-11-19:
I figured out how to change the model to mount a skr mine e3 v3 board.

[Mainboard Mount Pro - BTT SKR Mini E3 V3 v2.zip](https://github.com/bgdog1/3dPrinterCase/files/13402124/Mainboard.Mount.Pro.-.BTT.SKR.Mini.E3.V3.v2.zip)

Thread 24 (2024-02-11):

Heat inserts for raspberry pi … holes are way too big and m2.5 inserts aren’t listed in the bom

perfessor101, 2024-02-11:
Any build including a raspberry pi … holes are way too big in the mount (built pro combo) and m2.5 inserts aren’t listed anywhere.

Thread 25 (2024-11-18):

Display Mount PRO - LCD12864 too big

Xarnage, 2024-11-18:
The LCD12864 file is 200mm wide for the pro case and does not fit into the main body

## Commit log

2020-04-04 Begin using desktop app
    [Base Stand - Compact NO FEET.stl, Base Stand - Compact.f3d, Base Stand - Compact.stl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]
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2020-04-05 Create Front Vent - BTT.stl
    [Front Vent - BTT.stl]
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2020-04-20 Added mount for Orange Pi Lite
    [CPU Mount - Orange Pi Lite.stl]
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2020-04-26 Print at your own risk
    [Main Body V4_0 Compact.stl]
2020-05-03 Update Main Body V4_0 Compact.stl
    [Main Body V4_0 Compact.stl]
2020-05-03 Create Base Stand - Compact.stl
    [Base Stand - Compact.stl]
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2020-05-10 Update Main Body Rear V4_0 Standard - 2pc.stl
    [Main Body Rear V4_0 Standard - 2pc.stl]
2020-05-10 Removed Slim 2 pc stand
    [Base Stand Front Standard - Slim_2pc_wSwitch.stl, Base Stand Front Standard - Tall_2pc_wSwitch.stl, Base Stand Rear Standard - Slim_2pc_wSwitch.stl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]
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2020-05-12 adding a pushpin that can be used to hold base parts together
    [Press in Fastener for 2pc.stl]
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2020-05-25 Update Base Stand Rear Standard - Slim_2pc_wSwitch.stl
    [Base Stand Rear Standard - Slim_2pc_wSwitch.stl]
2020-06-01 Removed files for corrections
    [Base Stand Front Standard - Slim 2pc_wSwitch.stl, Base Stand Front Standard - Tall_2pc_wSwitch.stl, Base Stand Rear Standard - Slim_2pc_wSwitch.stl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]
2020-06-01 Fixed hole location
    [Base Stand Front Standard - Slim 2pc_wSwitch.stl, Base Stand Front Standard - Tall 2pc_wSwitch.stl, Base Stand Rear Standard - Slim 2pc_wSwitch.stl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]
2020-06-02 Update Mainboard Mount V4_0 - MKSGenL_centered.stl
    [Mainboard Mount V4_0 - MKSGenL_centered.stl]
2020-06-05 Create Mainboard Mount V4_0 - SKR GTR V1_0.stl
    [Mainboard Mount V4_0 - SKR GTR V1_0.stl]
2020-06-06 Create Mainboard Mount V4_0 - Duet_offset.stl
    [Mainboard Mount V4_0 - Duet_offset.stl]
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2020-07-19 Create Power Mount Panel - IEC Connector CR10.f3d
    [Power Mount Panel - IEC Connector CR10.f3d]
2020-07-22 Added New Base design
    [Base Stand - MeanWell 600w SE600 PSU OptionA.stl, Base Stand - MeanWell 600w SE600 PSU OptionB.stl, Base Stand - MeanWell 600w SE600 PSU.stl]
2020-07-24 Create CPU Mount - Blank.f3d
    [CPU Mount - Blank.f3d]
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2020-08-09 Create Main Body V3_5 Standard.stl
    [Main Body V3_5 Standard.stl]
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2020-08-15 Update Main Body V5_0 Standard.stl
    [Main Body V5_0 Standard.stl]
2020-08-15 Create Main Body V5_0 Compact.stl
    [Main Body V5_0 Compact.stl]
2020-08-15 Create Main Body V5_0 Standard.stl
    [Main Body V5_0 Standard.stl]
2020-08-15 Create Main Body V3_0 Compact wRPi.stl
    [Main Body V3_0 Compact wRPi.stl]
2020-08-16 Create Display Mount - Duet Panel 7i Base.stl
    [Display Mount - Duet Panel 7i Base.stl]
2020-08-19 Create Minboard Mount - SKR 1.4 wWIFI.stl
    [Minboard Mount - SKR 1.4 wWIFI.stl]
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2020-08-23 Update Main Body V5_0 Compact.stl
    [Main Body V5_0 Compact.stl]
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2020-09-03 Update Under Table Mainboard Case - Main Body.stl
    [Under Table Mainboard Case - Main Body.stl]
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2020-09-07 Update Main Body Rear Pro V5_0 - 2pc Standard.stl
    [Main Body Rear Pro V5_0 - 2pc Standard.stl]
2020-09-07 Update Main Body Front Pro V5_0 - 2 pc Standard.stl
    [Main Body Front Pro V5_0 - 2 pc Standard.stl]
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2020-09-22 Create Mainboard Mount Pro - SKR V1.X wMounts.stl
    [Mainboard Mount Pro - SKR V1.X wMounts.stl]
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2020-09-22 Create Base Stand Pro - wSwitch and IEC.stl
    [Base Stand Pro - wSwitch and IEC.stl]
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2020-09-22 Create Fan Mount - 4020mm DWT EXTRA Wide.stl
    [Fan Mount - 4020mm DWT EXTRA Wide.stl]
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2020-10-04 Create Display Mount - TFT35E3V30 SD Access Cover V2.stl
    [Display Mount - TFT35E3V30 SD Access Cover V2.stl]
2020-10-04 Create Display Mount - TFT35E3V30 SD Access Cover V3.stl
    [Display Mount - TFT35E3V30 SD Access Cover V3.stl]
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2020-10-09 Create Display Mount - TFT35E3V30 SD Access Flush Body.stl
    [Display Mount - TFT35E3V30 SD Access Flush Body.stl]
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2021-01-30 Added slot for wifi adapter on TFT35E3V3, added SKRE3Mini V2 mount for Pro case, added bases for mechanical relay and buck converter, added fan panel
    [Display Mount - TFT35E3V30 SD Access Body wifi slot.stl, Display Mount - TFT35E3V30 SD Access Cover V3 wifi.stl, Mainboard Mount Pro - Creality 115_SKR E3.f3d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]
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2021-02-06 Back panel with switch and cable holes. Reduced fan and buck converter mount to fit pro 2
    [CPU Mount - RPi 3B+ PRO case.stl, Rear Panel - 92mm fan cable and power holes.f3z, Rear Panel - 92mm fan cable and power holes.stl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]
2021-02-07 Create Display Mount Mini - TFT35E3V30 SD Access.stl
    [Display Mount Mini - TFT35E3V30 SD Access.stl]
2021-02-07 Update Display Mount Mini - TFT35E3V30 SD Access.stl
    [Display Mount Mini - TFT35E3V30 SD Access.stl]
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2022-03-13 Update Base Rear -Standard 2pc V2 wIEC Connector.stl
    [Base Rear -Standard 2pc V2 wIEC Connector.stl]
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2023-04-07 Create CPU Mount V2 - Orange Pi 3 LTS.stl
    [CPU Mount V2 - Orange Pi 3 LTS.stl]
2023-05-08 Update Mainboard Mount XL V5 - SKR V1.X.stl
    [Mainboard Mount XL V5 - SKR V1.X.stl]
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2023-05-21 Create E5 and 5 Pro - Side Skirt 6 Sided 10mm.stl
    [E5 and 5 Pro - Side Skirt 6 Sided 10mm.stl]
2023-05-25 Create E5 and 5 Pro - Front Skirt 6 Sided 10mm wUSB.stl
    [E5 and 5 Pro - Front Skirt 6 Sided 10mm wUSB.stl]
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2023-05-25 Update Ender 5 Single Display Box wFloor Ver. 3.stl
    [Ender 5 Single Display Box wFloor Ver. 3.stl]
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2023-08-20 Create MMV3 CV5 - SKR V3EZ.stl
    New file
    [MMV3 CV5 - SKR V3EZ.stl]
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
